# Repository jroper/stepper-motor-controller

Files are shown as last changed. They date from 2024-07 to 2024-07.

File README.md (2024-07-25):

# Stepper motor controller

This is the program for a stepper motor controller that I've built for controlling my equatorial platform for my dobsonian telescope. The parts that I've used to build this are:
 
* Arduino Nano V3.0 (equivalent) based on ATmega328
* A4988 stepper motor driver (though I'm replacing this with a TMC2209 because the A4988 is too loud)
* 200 step bipolar stepper motor
* Adafruit 14-segment LED Alphanumeric Backpack, with HT16K33 driver
* PEC11R Rotary encoder module with push button
* LED push button

I power the setup with a 12V 9Ah SLA battery. While the Nano can run off 12V with its own regulator, because I'm also powering the LED display off the Nano's 5V pin, I don't want to overload it, so I use a 7808 voltage regulator to drop the voltage to 8V before going to VIN. The Nano seems to be fine with that, my temperature measurements indicate it's only a few degrees above ambient.

The LED momentary push button is used to start/stop the motor. The LED itself is used to indicate if the motor is running or not.

The rotary encoder is used to configure it. The push button allows you to cycle through a menu, while the encoder allows you to set the value for the menu item being configured. When cycling through the menu, the menu title will scroll once across the display, before displaying the current value. Turning the encoder will cause it to stop scrolling and immediately display the value.

The menu items are:

* **Speed** - This is the speed of the stepper motor, measured in milliseconds between steps. Although it shows the speed down to 10ths of a microsecond, tuning it operates in 100 microsecond steps.
* **Fine** - This is for fine tuning the speed. It shows the speed down to the microsecond, and allows tuning it in microsecond increments. The most significant digit (ie, 10s of milliseconds) truncated.
* **Dimmer** - This controls the brightness of the display and running LED, and can be a value from 1 (least bright) to 16 (full brightness).
* **Idle minutes** - This is the number of minutes to wait before going into idle mode. In idle mode, an idle message scrolls across the screen. The motor will continue to run and can be turned on and off with the push button. To exit idle mode, push the menu button. Turning idle minutes below 1 will turn idle mode off.
* **Direction** - The direction that the motor will spin. The value can be zero or one. What these values mean depends on how you've wired the stepper motor, and how the motor is mechanically connected to your platform.

The settings are persisted to EEPROM between power off/on, there's a 10 second delay between when you've last change the settings and when it persists them to ensure the EEPROM isn't hammered (EEPROM is slow and only supports a limited number of erase/write cycles).

Unless your name is James too, I recommend changing the constants below for the welcome message and idle message.

This program uses a timer interrupt to drive the stepper motor, this ensures other things like menu operation and don't impact the stepper timing.

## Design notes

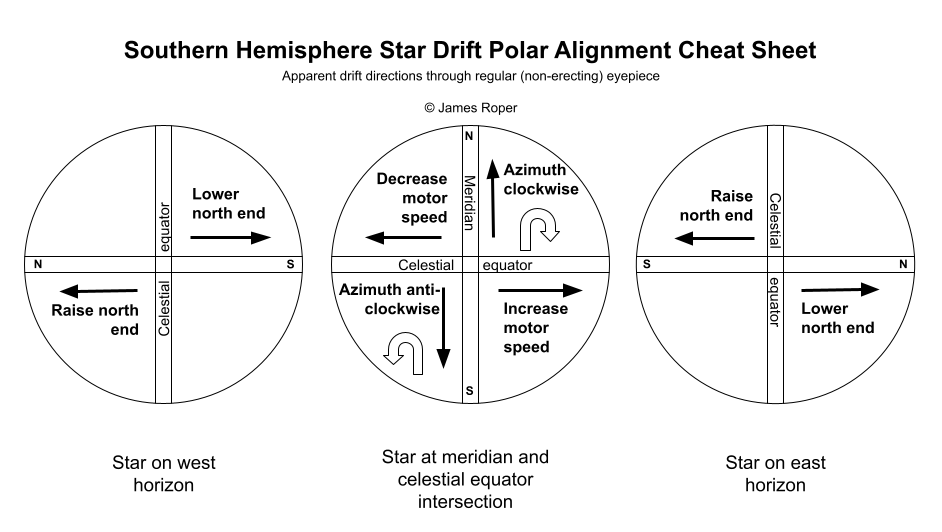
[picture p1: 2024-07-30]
telescope-alignment-cheatsheet.png

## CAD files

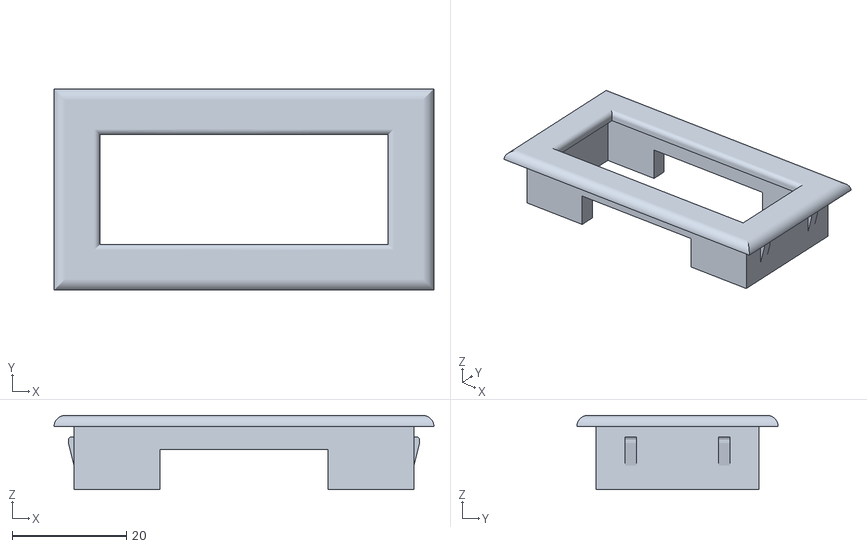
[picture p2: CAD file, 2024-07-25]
bezel.stl
66.4 x 35.2 x 13.0

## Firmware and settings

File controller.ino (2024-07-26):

// Copyright 2024 James Roper 
//
// Licensed under the Apache License, Version 2.0 (the "License");
// you may not use this file except in compliance with the License.
// You may obtain a copy of the License at
//
//     http://www.apache.org/licenses/LICENSE-2.0
//
// Unless required by applicable law or agreed to in writing, software
// distributed under the License is distributed on an "AS IS" BASIS,
// WITHOUT WARRANTIES OR CONDITIONS OF ANY KIND, either express or implied.
// See the License for the specific language governing permissions and
// limitations under the License.

/*
 * Stepper motor controller
 * ------------------------
 *
 * This is the program for a stepper motor controller that I've built for
 * controlling my equatorial platform for my dobsonian telescope. The
 * parts that I've used to build this are:
 * 
 * - Arduino Nano V3.0 (equivalent) based on ATmega328
 * - A4988 stepper motor driver (though I'm replacing this with a TMC2209
 *   because the A4988 is too loud)
 * - 200 step bipolar stepper motor
 * - Adafruit 14-segment LED Alphanumeric Backpack, with HT16K33 driver
 * - PEC11R Rotary encoder module with push button
 * - LED momentary push button
 *
 * I power the setup with a 12V 9Ah SLA battery. While the Nano can run off
 * 12V with its own regulator, because I'm also powering the LED display off
 * the Nano's 5V pin, I don't want to overload it, so I use a 7808 voltage
 * regulator to drop the voltage to 8V before going to VIN. The Nano seems to
 * be fine with that, my temperature measurements indicate it's only a few
 * degrees above ambient.
 *
 * The LED momentary push button is used to start/stop the motor. The LED
 * itself is used to indicate if the motor is running or not.
 *
 * The rotary encoder is used to configure it. The push button allows you to
 * cycle through a menu, while the encoder allows you to set the value for
 * the menu item being configured. When cycling through the menu, the menu
 * title will scroll once across the display, before displaying the current
 * value. Turning the encoder will cause it to stop scrolling and immediately
 * display the value.
 *
 * The menu items are:
 *
 * - Speed. This is the speed of the stepper motor, measured in milliseconds
 *   between steps. Although it shows the speed down to 10ths of a
 *   microsecond, tuning it operates in 100 microsecond steps.
 * - Fine. This is for fine tuning the speed. It shows the speed down to the
 *   microsecond, and allows tuning it in microsecond increments. The most
 *   significant digit (ie, 10s of milliseconds) truncated.
 * - Dimmer. This controls the brightness of the display and running LED, and
 *   can be a value from 1 (least bright) to 16 (full brightness).
 * - Idle minutes. This is the number of minutes to wait before going into
 *   idle mode. In idle mode, an idle message scrolls across the screen. The
 *   motor will continue to run and can be turned on and off with the push
 *   button. To exit idle mode, push the menu button. Turning idle minutes
 *   below 1 will turn idle mode off.
 * - Direction. The direction that the motor will spin. The value can be zero
 *   or one. What these values mean depends on how you've wired the stepper
 *   motor, and how the motor is mechanically connected to your platform.
 *
 * The settings are persisted to EEPROM between power off/on, there's a 10
 * second delay between when you've last change the settings and when it
 * persists them to ensure the EEPROM isn't hammered (EEPROM is slow and only
 * supports a limited number of erase/write cycles).
 *
 * Unless your name is James too, I recommend changing the constants below for
 * the welcome message and idle message.
 *
 * This program uses a timer interrupt to drive the stepper motor, this
 * ensures other things like menu operation and don't impact the stepper
 * timing.
 */

#include <EEPROM.h>
#include <Wire.h>
#include <Adafruit_GFX.h>
#include "Adafruit_LEDBackpack.h"
#define DISPLAY_ADDRESS 0x70
#define DEBOUNCE_MILLIS 100

const Adafruit_AlphaNum4 display = Adafruit_AlphaNum4();

// This should match the wiring of the board
#define STEP 4 // STEP PIN of the A4988 driver
#define DIR 5 // DIR PIN of the A4988 driver
#define ENABLE 2 // ENABLE PIN of the A4988 driver, active low
#define ROTARY_A 7 // Rotary encoder A PIN
#define ROTARY_B 8 // Rotary encoder B PIN
#define MODE_SWITCH 9 // Rotary encoder switch PIN
#define RUNNING_SWITCH 6 // Running switch PIN
#define RUNNING_LED 3 // Running LED PIN, must be PWM capable

// Welcome and idle messages, change these to whatever you want.
#define WELCOME_MESSAGE "HELLO JAMES"
#define IDLE_MESSAGE "ENJOY CLEAR SKIES JAMES"

// The default direction is anti-clockwise
#define DIRECTION LOW

// These are the configuration parameters for the program. On start up, we
// read the configuration from EEPROM, these defaults are only used the first
// time we get run on a particular device.

// Brightness of the display and running LED. A value from 1 to 16.
int brightness = 4;

// Stepper motor pulse delay in microseconds.
// 1.5 RPM for a 200 step motor with 16 micro steps, approximately what my
// platform needs.
unsigned int stepperDelayMicros = 12500;

// The number of minutes before the display goes into idle mode. Zero turns
// idle mode off.
int idleMinutes = 2;

// The direction
uint8_t direction = DIRECTION;

void setup() {
  eepromInitialRead();

  pinMode(STEP, OUTPUT);
  pinMode(DIR, OUTPUT);
  pinMode(ENABLE, OUTPUT);
  pinMode(RUNNING_LED, OUTPUT);
  pinMode(ROTARY_A, INPUT);
  pinMode(ROTARY_B, INPUT);
  pinMode(MODE_SWITCH, INPUT);
  pinMode(RUNNING_SWITCH, INPUT);

  // Setup the interrupt for the stepper. We start with it disabled, since we
  // want to explicitly turn the motor on whenever the board starts up. We're
  // using timer1 because this gives us 16 bits of precision, which allows
  // microsecond accuracy for pulse delays of up to 65ms.
  cli();
  // Initialization, set everything to zero.
  TCCR1A = 0;  // set entire TCCR1A register to 0
  TCCR1B = 0;  // same for TCCR1B
  TCNT1 = 0;   // initialize counter value to 0
  TIMSK1 = 0;  // initially we're disabled
  // We're running with an 8x prescaler, clock rate of 16Mhz, so the timer tick will be
  // 2Mhz. If we want to step every X microseconds, we need to interrupt at half that
  // delay, to send the high then low signals. So with two ticks at each microsecond
  // setting the compare match register to the micro second delay will do that.
  OCR1A = stepperDelayMicros;
  // turn on CTC mode
  TCCR1B |= (1 << WGM12);
  // 8x prescaler
  TCCR1B |= (1 << CS11);
  // Comment the above and uncomment the below to enable 1024x prescaling, useful for
  // development when flashing an LED rather than the motor
  // TCCR1B |= (1 << CS12) | (1 << CS10);
  sei();

  // Initialize the display
  display.begin(DISPLAY_ADDRESS);
  display.setBrightness(brightness);
  display.clear();

  // Initialize direction of the stepper motor
  digitalWrite(DIR, direction);
  // Ensure we start disabled - the ENABLE pin is active low.
  digitalWrite(ENABLE, HIGH);

  // read the encoder to initialise it
  readEncoder();

  // Display the welcome message, then display the first menu value.
  displayScrollOnce(WELCOME_MESSAGE, []() {
    displayUnsignedNumber(stepperDelayMicros / 10, 1);
  });
}

void loop() {
  inputLoop();
  displayLoop();
  eepromLoop();
}

/***********
 * Stepper *
 ***********/
bool running = false;
int stepState = LOW;

// Interrupt service routine for stepping
ISR(TIMER1_COMPA_vect) {
  if (stepState == LOW) {
    stepState = HIGH;
    digitalWrite(STEP, HIGH);
  } else {
    stepState = LOW;
    digitalWrite(STEP, LOW);
  }
}

/* Update the compare match register to the currently configured delay */
void updateStepperCMR() {
  // Because this is a long, we should disable interrupts while we write it to
  // ensure we don't write an inconsistent value.
  cli();
  OCR1A = stepperDelayMicros;
  sei();
}

void stop() {
  TIMSK1 = 0;  // disable timer1 interrupt

  running = false;
  stepState = LOW;
  digitalWrite(ENABLE, HIGH);
  digitalWrite(STEP, 0);
  analogWrite(RUNNING_LED, 0);
}

/*
 * Set the brightness of the running LED to the configured brightness, but
 * only if running. This is used to turn on the LED when we start running too.
 */
void updateRunningLedBrightness() {
  if (running) {
    analogWrite(RUNNING_LED, map(brightness, 1, 16, 4, 255));
  }
}

void start() {
  running = true;
  updateRunningLedBrightness();
  digitalWrite(DIR, direction);
  digitalWrite(ENABLE, LOW);
  // Docs say to wait a millisecond before sending ticks to the motor
  delay(1);

  TCNT1 = 0;                // set timer1 counter back to zero
  TIMSK1 |= (1 << OCIE1A);  // enable timer1 interrupt
}

/**********
 * EEPROM *
 **********/
// Magic string that gets written to the data first. This is used to detect if
// we're running on a device that hasn't been run on before, so that we don't
// load garbage. If we change the format of the EEPROM data, we can change this
// to "reset" it.
#define MAGIC "eqpf01"
// Writing to EEPROM is slow (takes multiple milliseconds), and EEPROM has
// limited erase/write cycles, so we don't want to write to it on every change
// of data. Instead, we wait until there's been no updates for 10 seconds, and
// then we persist.
#define EEPROM_PERSIST_DELAY_MILLIS 10000  // 10 seconds

// Set when any of our config params has been updated, but not yet persisted.
bool eepromDirty = false;
// When the last update happened.
unsigned long eepromLastUpdateMillis;

struct EepromData {
  // Must be the length of MAGIC plus one (for null terminator).
  char magic[7];
  unsigned int stepperDelayMicros;
  int brightness;
  int idleMinutes;
  uint8_t direction;
};

void eepromInitialRead() {
  EepromData data;
  EEPROM.get(0, data);
  // Check that the magic string in the EEPROM matches our magic string. If so,
  // use the data.
  if (strcmp(data.magic, MAGIC) == 0) {
    stepperDelayMicros = data.stepperDelayMicros;
    brightness = data.brightness;
    idleMinutes = data.idleMinutes;
    direction = data.direction;
  } else {
    // Otherwise, persist the default data.
    eepromPersist();
  }
}

void eepromPersist() {
  EepromData data;
  strcpy(data.magic, MAGIC);
  data.stepperDelayMicros = stepperDelayMicros;
  data.brightness = brightness;
  data.idleMinutes = idleMinutes;
  data.direction = direction;
  EEPROM.put(0, data);
}

void eepromLoop() {
  if (eepromDirty && millis() - eepromLastUpdateMillis > EEPROM_PERSIST_DELAY_MILLIS) {
    eepromDirty = false;
    eepromPersist();
  }
}

void eepromTouch() {
  eepromDirty = true;
  eepromLastUpdateMillis = millis();
}

/******************
 * INPUT HANDLING *
 ******************/
// Idle is a special mode, we can't cycle into it, but when in the idle mode,
// if we push the mode button, we'll end up in the speed mode.
#define CONFIG_MODE_IDLE -1
#define CONFIG_MODE_SPEED 0
#define CONFIG_MODE_FINE 1
#define CONFIG_MODE_BRIGHTNESS 2
#define CONFIG_MODE_IDLE_MINUTES 3
#define CONFIG_MODE_DIRECTION 4
// The number of config modes.
#define CONFIG_MODES 5

int configMode = CONFIG_MODE_SPEED;
bool debouncing = false;
unsigned long debounceStartMillis = 0;

// These are used for a debouncing rotary encoder.
uint8_t oldAB = 3;                                                                      // Lookup table index
int8_t encoderValue = 0;                                                                // Encoder value
const int8_t encoderStates[] = { 0, -1, 1, 0, 1, 0, 0, -1, -1, 0, 0, 1, 0, 1, -1, 0 };  // Lookup table

// The rotary encoder switch is LOW active, so we need to start HIGH.
int modeSwitchState = HIGH;
int runningSwitchState = LOW;

unsigned long idleStartMillis = 0;

void inputLoop() {
  int encDir = readEncoder();
  if (encDir != 0) {
    idleReset();
    handleEncoderTurn(encDir);
  }

  // Global debounce. We don't expect multiple switches to be pushed at the
  // same time, so when any switch changes state, we wait for the debounce
  // delay before accepting any further input from any switch.
  if (debouncing) {
    if (millis() - debounceStartMillis >= DEBOUNCE_MILLIS) {
      debouncing = false;
    } else {
      return;
    }
  }

  if (pushed(MODE_SWITCH, &modeSwitchState, LOW)) {
    // Reset start time for idle timeout.
    idleReset();
    configMode = (configMode + 1) % CONFIG_MODES;
    switch (configMode) {
      case CONFIG_MODE_SPEED:
        displayScrollOnce("SPEED", []() {
          displayUnsignedNumber(stepperDelayMicros / 10, 1);
        });
        break;
      case CONFIG_MODE_FINE:
        displayScrollOnce("FINE", []() {
          displayUnsignedNumber(stepperDelayMicros, 0);
        });
        break;
      case CONFIG_MODE_BRIGHTNESS:
        displayScrollOnce("DIMMER", []() {
          displayUnsignedNumber(brightness, 4);
        });
        break;
      case CONFIG_MODE_IDLE_MINUTES:
        displayScrollOnce("IDLE MINUTES", []() {
          if (idleMinutes == 0) {
            displayStaticText("Off", 4);
          } else {
            displayUnsignedNumber(idleMinutes, 4);
          }
        });
        break;
      case CONFIG_MODE_DIRECTION:
        displayScrollOnce("DIRECTION", []() {
          displayUnsignedNumber(direction, 4);
       });
       break;
    }
  }

  if (pushed(RUNNING_SWITCH, &runningSwitchState, HIGH)) {
    if (running) {
      stop();
    } else {
      start();
    }
  }

  if (idleMinutes > 0 && configMode != CONFIG_MODE_IDLE && millis() - idleStartMillis > idleMinutes * 60000l) {
    // If we've been idle for the configured idle minutes, go into idle mode.
    configMode = CONFIG_MODE_IDLE;
    displayScroll(IDLE_MESSAGE);
  }
}

void idleReset() {
  idleStartMillis = millis();
}

void handleEncoderTurn(int encDir) {
  switch (configMode) {
    case CONFIG_MODE_SPEED:
      updateStepperDelayMicros(encDir * 100);
      displayUnsignedNumber(stepperDelayMicros / 10, 1);
      break;
    case CONFIG_MODE_FINE:
      updateStepperDelayMicros(encDir);
      displayUnsignedNumber(stepperDelayMicros, 0);
      break;
    case CONFIG_MODE_BRIGHTNESS:
      brightness += encDir;
      if (brightness < 1) {
        brightness = 1;
      } else if (brightness > 16) {
        brightness = 16;
      }
      display.setBrightness(brightness);
      updateRunningLedBrightness();
      displayUnsignedNumber(brightness, 4);
      break;
    case CONFIG_MODE_IDLE_MINUTES:
      idleMinutes += encDir;
      if (idleMinutes < 0) {
        idleMinutes = 0;
      } else if (idleMinutes > 30) {
        idleMinutes = 30;
      }
      if (idleMinutes == 0) {
        displayStaticText("Off", 4);
      } else {
        displayUnsignedNumber(idleMinutes, 4);
      }
      break;
    case CONFIG_MODE_DIRECTION:
      direction ^= HIGH;
      // This isn't needed, but when I first ran this on my Arduino I had a
      // bug and the value was set to 255, this ensures it's either 1 or 0.
      // This will fix any such data corruptions.
      direction &= HIGH;
      displayUnsignedNumber(direction, 4);
      break;

    case CONFIG_MODE_IDLE:
      return;
  }
  eepromTouch();
}

void updateStepperDelayMicros(int increment) {
  stepperDelayMicros += increment;
  if (stepperDelayMicros < 1000) {
    stepperDelayMicros = 1000;
  }
  if (stepperDelayMicros > 60000) {
    stepperDelayMicros = 60000;
  }
  updateStepperCMR();
}

/* Returns true if the button has changed state from up to down */
bool pushed(int pin, int *lastState, int pushedState) {
  int state = digitalRead(pin);
  if (state != *lastState) {
    debouncing = true;
    debounceStartMillis = millis();
    *lastState = state;
    return *lastState == pushedState;
  } else {
    return false;
  }
}

int readEncoder() {
  oldAB <<= 2;  // Remember previous state

  if (digitalRead(ROTARY_A)) oldAB |= 0x02;
  if (digitalRead(ROTARY_B)) oldAB |= 0x01;

  encoderValue += encoderStates[(oldAB & 0x0f)];

  if (encoderValue > 3) {
    encoderValue = 0;
    return -1;
  } else if (encoderValue < -3) {
    encoderValue = 0;
    return 1;
  }
  return 0;
}

/********************
 * DISPLAY HANDLING *
 ********************/
#define DISPLAY_MODE_SCROLL_ONCE 0
#define DISPLAY_MODE_SCROLL 1
#define DISPLAY_MODE_STATIC 2
#define DISPLAY_SCROLL_DELAY_MILLIS 300
String displayText;
void (*displayNext)();
unsigned int displayMode;
int displayPointer;
long displayLastRenderMillis;

/*
 * Scroll the given text once, and once done, invoke the passed in next
 * function. Typically, the next function should tell the display what to
 * display next.
 *
 * Note that if any other method to display something is invoked while
 * scrolling is happening, that will change the display mode and display
 * whatever that method requires. This means after entering a mode, the
 * operator can start immediately using the rotary encoder and it because
 * that updates the display as you increment through the value, the scrolling
 * will stop and the value will be displayed.
 */
void displayScrollOnce(String text, void (*next)()) {
  displayText = text;
  displayNext = next;
  displayMode = DISPLAY_MODE_SCROLL_ONCE;
  displayPointer = 0;
  displayRenderScroll();
}

/**
 * Display the given text, scrolling continuously.
 */
void displayScroll(String text) {
  displayText = text;
  displayMode = DISPLAY_MODE_SCROLL;
  displayPointer = 0;
  displayRenderScroll();
}

/*
 * Display the given number, inserting a decimal point at the given position.
 * If number > 9999, the most significant digits will be trimmed. If decimalPos
 * >= 4, no decimal point will be shown.
 */
void displayUnsignedNumber(unsigned int number, int decimalPos) {
  String text = String(number % 10000);
  displayStaticText(text, decimalPos);
}

/*
 * Display the given text. If text is more than four characters, the last four
 * characters will be displayed.
 */
void displayStaticText(String text, int decimalPos) {
  displayMode = DISPLAY_MODE_STATIC;
  for (int i = 0; i < 4; i++) {
    int nextCharIndex = text.length() - 4 + i;
    if (nextCharIndex < 0) {
      if (i >= decimalPos) {
        display.writeDigitAscii(i, '0', decimalPos == i);
      } else {
        display.writeDigitAscii(i, ' ');
      }
    } else {
      display.writeDigitAscii(i, text.charAt(nextCharIndex), decimalPos == i);
    }
  }
  display.writeDisplay();
}

void displayLoop() {
  switch (displayMode) {
    case DISPLAY_MODE_SCROLL_ONCE:
      if (millis() - displayLastRenderMillis >= DISPLAY_SCROLL_DELAY_MILLIS) {
        // If we've reached the end of the text to display, invoke the next
        // callback.
        if (displayPointer >= displayText.length() + 4) {
          displayNext();
        } else {
          displayRenderScroll();
        }
      }
      break;
    case DISPLAY_MODE_SCROLL:
      if (millis() - displayLastRenderMillis >= DISPLAY_SCROLL_DELAY_MILLIS) {
        // If we've reached the end of the text to display, reset to the
        // beginning.
        if (displayPointer >= displayText.length() + 4) {
          displayPointer = 0;
        }
        displayRenderScroll();
      }
      break;
  }
}

/* Render the next scroll increment */
void displayRenderScroll() {
  for (int i = 0; i < 4; i++) {
    int toDisplay = displayPointer - 4 + i;
    if (toDisplay >= 0 && toDisplay < displayText.length()) {
      display.writeDigitAscii(i, displayText.charAt(toDisplay));
    } else {
      display.writeDigitAscii(i, ' ');
    }
  }
  display.writeDisplay();
  displayPointer++;
  displayLastRenderMillis = millis();
}

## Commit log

2024-07-25 Added bezel STL file
    [bezel.stl]
2024-07-26 Switched from using SLEEP pin to ENABLE pin
    The TMC2209 doesn't have a SLEEP pin, so I switched to turning the motor on/off
    using the ENABLE PIN, which required reversing the HIGH/LOW settings for
    on/off.
    [controller.ino]
